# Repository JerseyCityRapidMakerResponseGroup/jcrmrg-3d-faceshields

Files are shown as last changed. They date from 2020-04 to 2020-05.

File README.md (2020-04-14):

# jcrmrg-3d-faceshields
## Overview
[Jersey City Rapid Makers Response Group](https://jcrmrg.org) - 3D printing files for faceshields  
The JCRMRG is printing faceshields for the local medical establishments to help bolster supplies.
The group is also actively discussing filling other PPE needs for the local medical establishments, but this repo is specifically geared towards printing facemasks.
Any help or support are welcome.

---

### Additional Information
These faceshields can be printed on most 3d printers.  **Please be aware that gcode may not work on, and may possibly damage, other printers**.

## Contribution Instructions

<details>
  <summary>I'm all in</summary>

  Great, first go to our [site and sign up](https://jcrmrg.org/join).  
  After fully onboarding you will be able to contribute to the repo, but it is not required.
  Follow the guides below for pulling the repo and contributing.
  In the meantime you can download the gcode or Cura projects and start printing.

  #### Requirements:
  * Git
  * Cura
  * Write access to the repo (contact @timothyjryan)

  #### Get the repository
  ```
  cd <where to keep local copy>
  git clone https://github.com/JerseyCityRapidMakerResponseGroup/jcrmrg-3d-faceshields
  ```
  #### Edit projects
  *gcode and zips are ignored by git intentionally*
  **Make sure to pull the repository before doing any work**

  `git pull`

  Use Cura to open a project in the projects folder or save a new project to that folder.
  Then push it to the repo.
  
  ```
  git add . # adds everything, alternatively git add <file>
  git commit -m "Some description about the change made to the file"
  git push
  ```

  #### Upload gcode
  Go to the [Releases](https://github.com/JerseyCityRapidMakerResponseGroup/jcrmrg-3d-faceshields/releases) page.  
  Add a new draft. The uploaded file should be a zip of the gcode and the Cura project.  
  **Please be sure that different files have different major version numbers (v1.x, v2.x, etc.).
  This is not exactly how versioning should be used, but it will be the easiest to maintain for our purposes.**

</details>

<details>
  <summary>I have or am getting a printer, but don't want to do meetings/discord/etc.</summary>
  
  Copy the Cura projects for either the Prusa or Verskstan models from this repo (or clone the repo).
  Print what you can and message [admin@jcrmrg.org](mailto:admin@jcrmrg.org) to discuss drop off.
  If you run into printing problems please [sign up](https://jcrmrg.org/join) with our group. 
  We have an active maker community for troubleshooting.

</details>

## Faceshield Models
[Verkstan](https://3dprint.nih.gov/discover/3dpx-013306)  
[Prusa](https://www.prusa3d.com/covid19/)

## File table
All gcode files are in the [Releases](https://github.com/timothyjryan/jcrmrg-3d-faceshields/releases).
Cura project files and gcodes are zipped, but Cura projects can also be found in the projects directory.
The gcodes are set up as releases due to file size restrictions (the gcode files are pretty big).
Please pay attention to the bed size, material type and nozzle size when using Cura projects from this repository.

### Naming Convention

Names will be \<Printer Designation\>\_\<Material\>\_\<Model\>\_\<Model details\>\_qty\<stack quantity\>.\<filetype\>

| Acronym | Type | Full Name |
|--- |--- |--- |
|E3 | Printer  | Ender 3 (Pro) |
|PLA | Material | PLA |
|PETG | Material | PETG |
  
### Files
*Information below reflects the latest version of the files*
<details>
  <summary>E3_PLA_Verkstan_NA_Stacked_noz0.4mm_qty20</summary>
  
  1. **Description:** #JCRMRG branded 2x10 stack of Verkstan NA 6 hole punch using PLA
  1. **Estimated Time:** 18H37M
  1. **Actual Time:** 
  1. **Additional Notes:**
      1. No slowdown on 1st layer of stacks
      1. 0.4mm Nozzle gcode
      1. Concentric floor        
</details>

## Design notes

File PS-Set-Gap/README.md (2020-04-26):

# Overview
This script will go through gcode and modify the gap between stacked members.  
**Please note that this has only been tested with gcode produced from Cura slicer 
with no additional post processing (other than comment based). There is a very 
good chance that this will break any post processing that includes Z moves or 
movement speed changes (E values should be fine).**

## Description
The script finds stacked members by evaluating the gap between a Z<sub>n-1</sub> and Z<sub>n</sub>. 
**Your gcode must already have a gap in it (gap created in Cura) with a non-zero 
value to work. The script won't be able to differentiate between the stack members 
if there isn't a gap already created by the slicer.** It then flags all occurances of Z afterwards to be incremented by a multiplier of the added height (original gap height + gap addition) if the difference is
greater than the defined gap height. The supporting 'awk' folder is required
and it must remain in the same directory as the powershell script file. **New 
troubleshooting functionality has been added in: the awk script puts a line that
starts with `; PS-SET-GAP => <details>` before each modified line.**

---

### Parameter $Path
This is the gcode file to be edited.  The original file will be unmodified and
renamed with '.orig' appended.  Subsequent calls of this script will overwrite,
without prompting, both the .orig and the .gcode files.

### Parameter $GapHeight
This is the gap height that the models were originally sliced with. The models
have to be sliced with a gap that is a multiplier of the layer height (at least
for Cura) otherwise the slicer will have gaps between some models and no gaps 
between others.

### Parameter $GapAddition
This is the additional gap height that you would like to add between stacked
models.  An original gap height of 0.32 with a gap addition of 0.18 will result
in the gcode having Z moves of 0.5 between models.

### Parameter $FirstLayerSpeed
Value is in mm/s (NOT mm/min AS IN RAW GCODE). This parameter is optional and
will only adjust the gcode if set. The awk script uses the same criteria to 
determine all the lines of the first layers of each stack member and updates 
the speed accordingly.

### Examples
```PowerShell
Set-Gap.ps1 -Path ..\E3_Verkstan_NA_qty10.gcode `
  -GapHeight 0.32 `
  -GapAddition 0.18
# Produces files:
# *E3_Verkstan_NA_qty10.gcode*
# *E3_Verkstan_NA_qty10.gcode.orig* 
```

```PowerShell
Set-Gap.ps1 -Path ..\E3_Verkstan_NA_qty10.gcode `
  -GapHeight 0.32 `
  -GapAddition 0.18 `
  -FirstLayerSpeed 15
# Produces files:
# *E3_Verkstan_NA_qty10.gcode*
# *E3_Verkstan_NA_qty10.gcode.orig* 
```

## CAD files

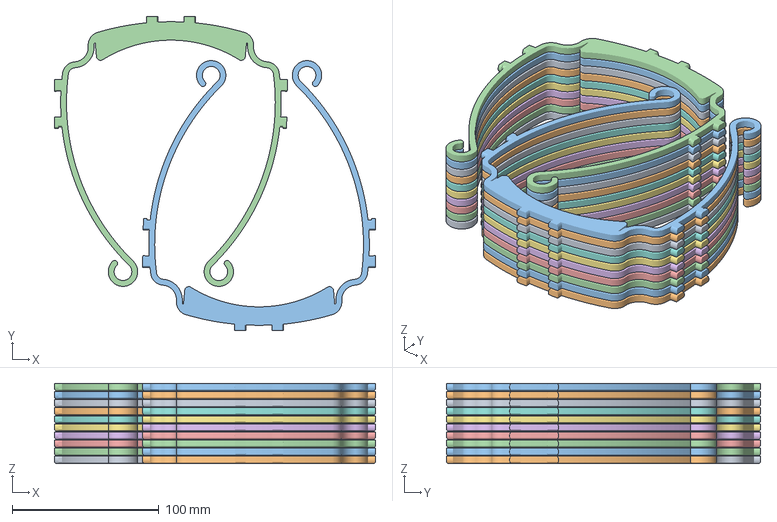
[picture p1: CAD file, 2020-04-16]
projects/DS-verkstan_20x_10hr_.8mm.3mf
218.5 x 213.6 x 54.5 mm

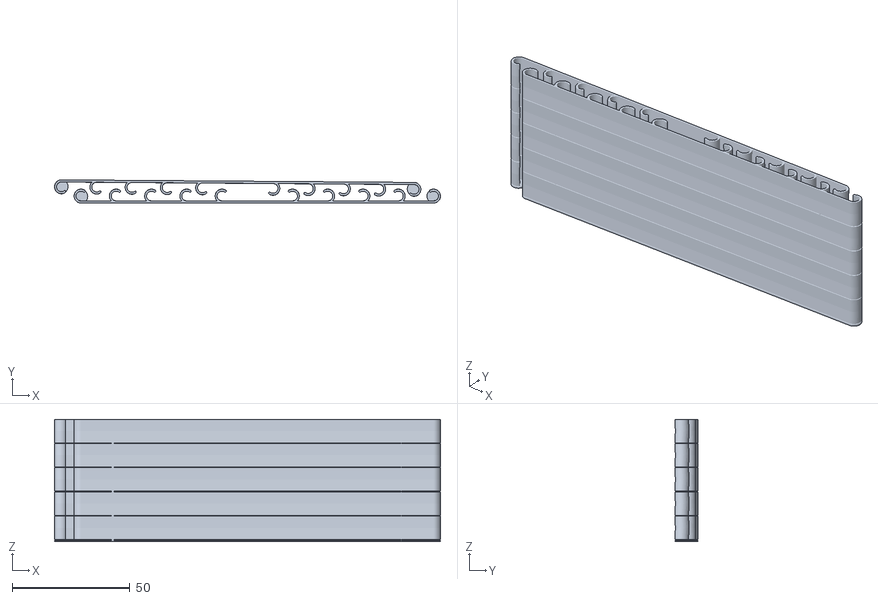
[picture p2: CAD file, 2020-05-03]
stl/ear_saver_stacked_300um_layers.stl
164.2 x 9.90 x 52.1

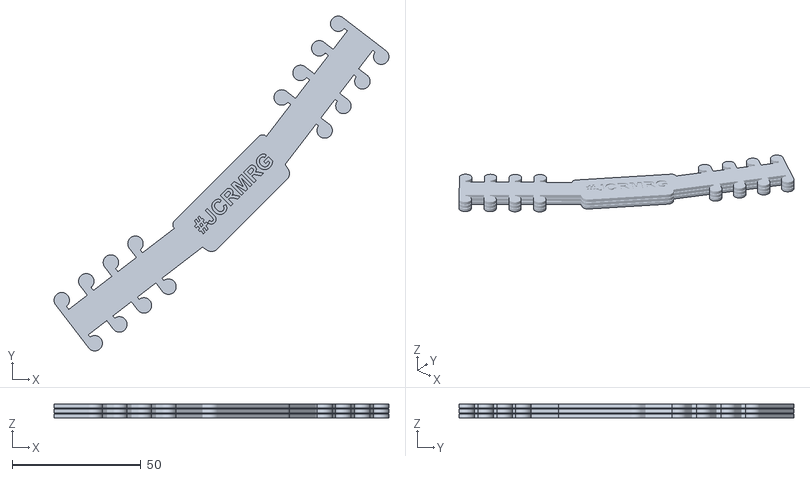
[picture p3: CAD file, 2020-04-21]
stl/saver .4 space 3 stack.stl
129.9 x 129.9 x 5.30

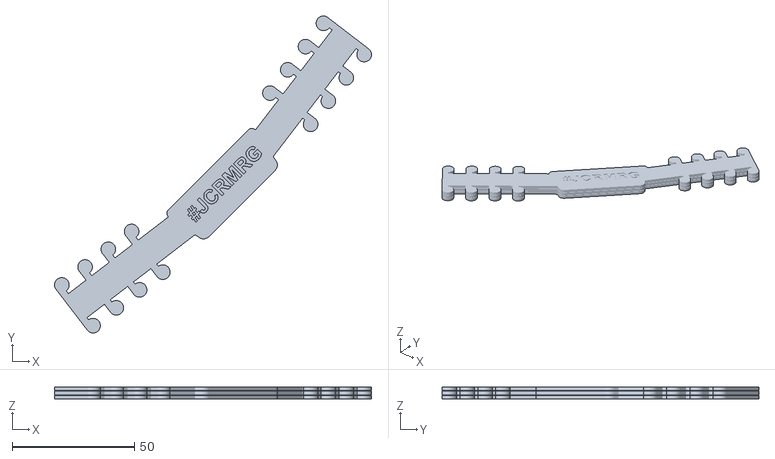
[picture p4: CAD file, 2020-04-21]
stl/saver .2 space 3 stack.stl
129.9 x 129.9 x 4.90

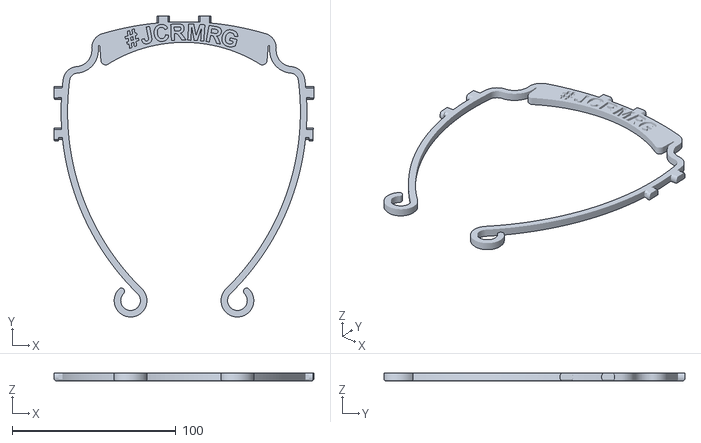
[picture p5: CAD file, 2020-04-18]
stl/Verk_NA_V5_BIGLOGO.stl
158.5 x 183.6 x 5.00

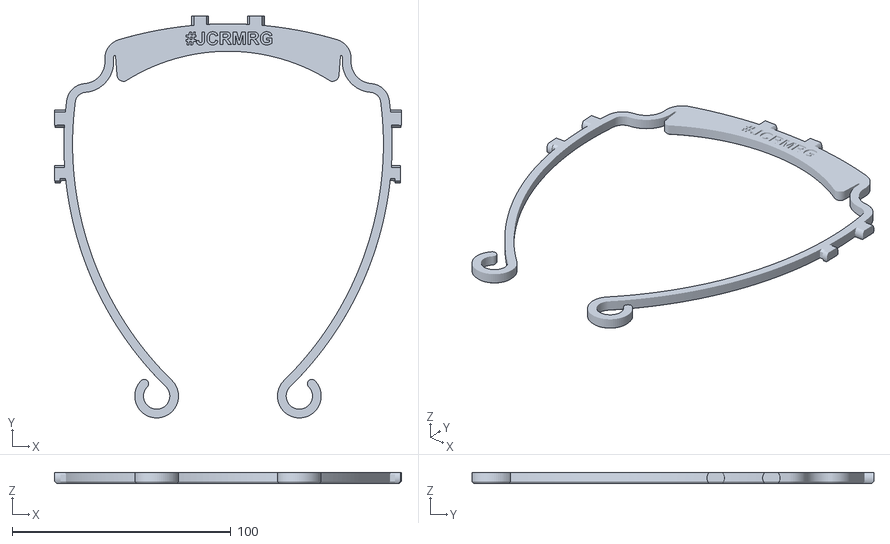
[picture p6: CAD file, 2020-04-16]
stl/Visor_Frame_NORTH_AMERICA_letter_6-hole_v5-solid_front with logo.stl
158.5 x 183.6 x 5.00

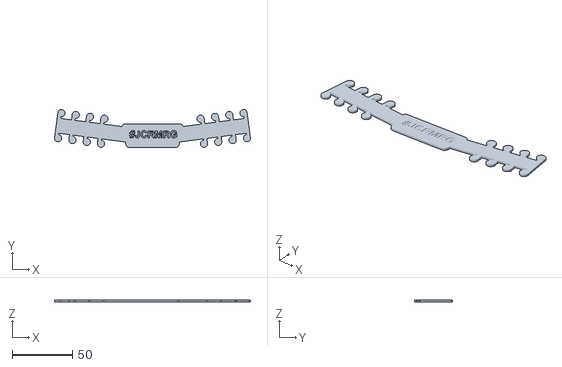
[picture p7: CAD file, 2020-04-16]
stl/Ear Saver with Logo 1.5mm thick .stl
163.1 x 31.6 x 1.50

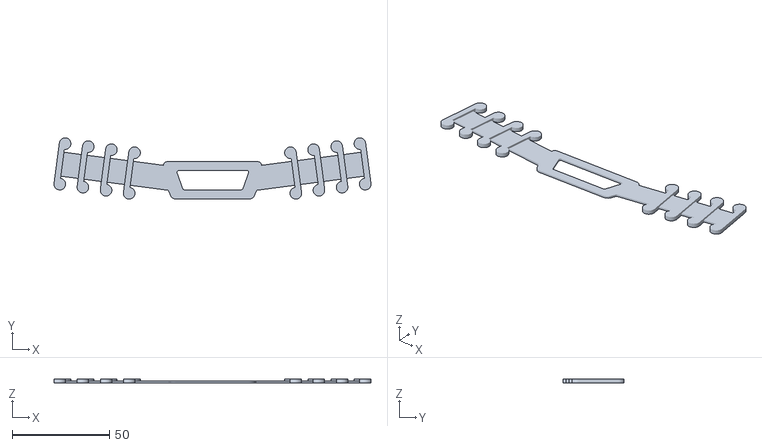
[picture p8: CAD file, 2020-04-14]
stl/Surgical_Mask_Strap_Remix_0.stl
163.0 x 31.5 x 2.00

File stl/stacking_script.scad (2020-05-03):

//
// Simple script to make a stacked version of the basic input STL.
// Adjust params as needed
//

//The number of instances of the model to stack
num_to_stack=20;
//The layer height you plan to print at
layer_height=0.3;
//Nozzle size
nozzle_size=0.4;
//The size of gap between stacked copies of the model
//we recommend 1 * layer_height but this can vary by printer.
stack_gap=2*layer_height;
//The height of the model you'd like the stack
model_height=5;
//The path to the STL that you'd like to stack.
model_path="./Visor_Frame_NORTH_AMERICA_letter_6-hole_v5-1mm_front.stl";


rotate([180,0,0])
union(){
    for (i = [0 : num_to_stack]){
        translate([0, 0,(model_height+stack_gap) * i]){
            if(i > 0){
                
                    intersection(){
                        translate([0,0,-stack_gap])
                        import(model_path);
                for (i = [0 : 12]){
                        union(){
                            
                        if(i < 8){
                            translate([-100, 28+(-22*i),-stack_gap]){
                                color("blue")
                                cube([200,nozzle_size,stack_gap]);
                            }
                        }
                        
                        if(i >2 && i < 7){
                            translate([-35 -(i*7), -5,-stack_gap]){
                                color("green")
                               cube([nozzle_size,20,stack_gap]);
                            }
                            
                            translate([96 -(i*7), -5,-stack_gap]){
                                color("green")
                               cube([nozzle_size,20,stack_gap]);
                            }
                        }
                        
                        
                        translate([-100, -138,-stack_gap]){
                            color("red")
                            cube([200,nozzle_size,stack_gap]);
                        }
                        
                        translate([-100, -143,-stack_gap]){
                            color("red")
                            cube([200,nozzle_size,stack_gap]);
                        }
                        
                        if(i >2 && i < 7){
                            translate([110 -(i*25), 0,-stack_gap]){
                                color("purple")
                               cube([nozzle_size,35,stack_gap]);
                            }
                        }
                        
                        if(i >2 && i < 7){
                            translate([-70 -(i*2), -45,-stack_gap]){
                                color("yellow")
                               cube([nozzle_size,40,stack_gap]);
                            }
                            
                            translate([88 -(i*2), -45,-stack_gap]){
                                color("yellow")
                               cube([nozzle_size,40,stack_gap]);
                            }
                        }
                        
                           if(i < 7){
                            translate([32 -(i*16), -152,-stack_gap]){
                                color("red")
                               cube([nozzle_size,10,stack_gap]);
                            }
                        }
                    }
                    }
                }
            }
            import(model_path);
        }
    }
}

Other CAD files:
stl/Visor_Frame_NORTH_AMERICA_letter_6-hole_v5-solid_front.stl
stl/Visor_Frame_NORTH_AMERICA_letter_6-hole_v5-1mm_front.stl
stl/verkstan with jcrmrg logo.stl

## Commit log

2020-04-12 Adding Cura project file for 20 stack of verkstan
    [E3_PLA_Verkstan_NA_Stacked_qty20.3mf]
2020-04-12 The gcodes are too big
    gcode and Cura project files are zipped and uploaded as releases
    [E3_PLA_Verkstan_NA_Stacked_qty20.3mf]
2020-04-13 Added note about nozzle size
2020-04-14 Add files via upload
    Verkstan American 6 pin version with #JCRMRG
    [verkstan with jcrmrg logo.stl]
2020-04-14 File reorganization
    [E3_PLA_Verkstan_NA_Stacked_qty20.3mf, verkstan with jcrmrg logo.stl]
2020-04-14 Updated Cura project to use branded design
    [E3_PLA_Verkstan_NA_Stacked_qty20.3mf]
2020-04-14 Renamed to include nozzle size
    [E3_PLA_Verkstan_NA_Stacked_noz0.4mm_qty20.3mf]
2020-04-14 Updating contributor info
    [E3_PLA_Verkstan_NA_Stacked_noz0.4mm_qty20.3mf, E3_PLA_Verkstan_NA_Stacked_noz0.4mm_qty3.3mf]
2020-04-14 NIH Approve Surgical Mask Strap
    "Ear Saver" Strap used for surgical masks
    Approved by NIH: https://3dprint.nih.gov/discover/3dpx-013410
    Instructions advise printing at 85% size: "100% for larger heads/hairdos and 85% for average"
    [Surgical_Mask_Strap_Remix_0.stl]
2020-04-16 DanS version - Dual 10 stacks, .8mm nozzle
    Dual 10 stacks, runs hot for Inland PLA, one layer gap, gcode has been edited to slow first layer after gap.
    Settings:
    .5mm layer height
    .8mm line width
    3 walls/tops/bottoms
    .5mm gap between models
    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
    [DS-verkstan_20x_10hr_.8mm.3mf]
2020-04-16 Reorganizing files to folders
    [DS-verkstan_20x_10hr_.8mm.3mf, Surgical_Mask_Strap_Remix_0.stl, Visor_Frame_NORTH_AMERICA_letter_6-hole_v5-1mm_front.stl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]
2020-04-16 Floor falling through at center
    [E3_PLA_Verkstan_NA_Stacked_noz0.4mm_qty3.3mf]
2020-04-22 Adding an openscad script to create basic stacks of an input STL with basic parameterization.
    [stacking_script.scad]
2020-04-22 Adding break away supports for curved surfaces at stack interface layers
    [stacking_script.scad]
2020-04-26 adding a powershell tool for adjusting stack gaps
2020-05-01 Improving break away supports and switching to the no-logo visor
    [stacking_script.scad]
2020-05-03 Adding stacked ear saver for 0.3mm layer height using the new design
    [ear_saver_stacked_300um_layers.stl]
